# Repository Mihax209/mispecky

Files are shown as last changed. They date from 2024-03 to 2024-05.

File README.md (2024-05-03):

# MiSpecky LED Spectrum analyzer
MiSpecky is an arduino-based project for and LED strip audio spectrum analyzer. It uses hardware components for the audio frequency slicing, so it has incredibly fast response times, and not much software delay.

(The GIF takes a few moments to load...)  
MiSpecky
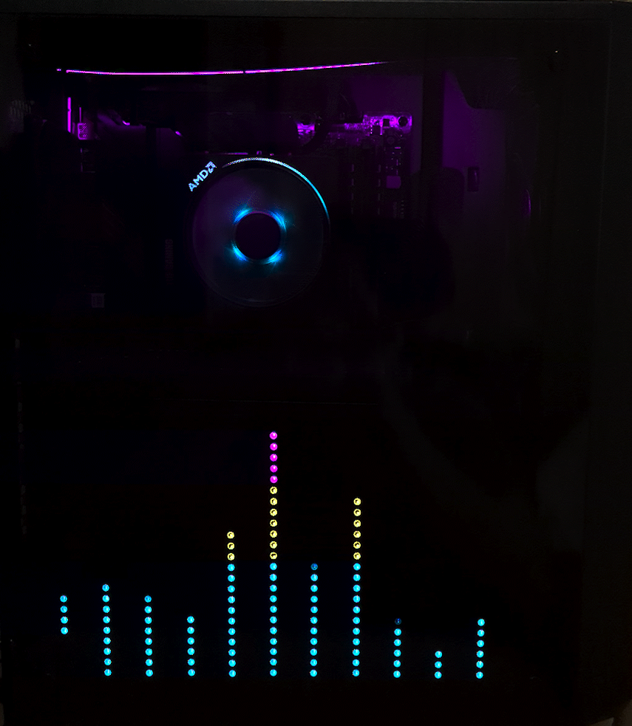
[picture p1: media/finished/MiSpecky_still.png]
MiSpecky Still


The intention was to incorporate it into my PC's case (Fractal Design Meshify C)

## Overview
The components of this project are:
- Arduino Mega Board
- Custom PCB board that acts as an shield/hat
    - along with accompanying hardware components
- LED strip assembled onto a board
- [Companion GUI controller application](https://github.com/Mihax209/mispecky-gui-controller)

## Video demonstration
This video showcases the box and companion GUI app features

https://www.youtube.com/watch?v=yOwKhR_m7uo

## Arduino+Shield Box
The PCB is basically only a carrier board for the two MSGEQ7 chips (IC1/2) responsible for the audio splicing.

The Si5351A board (U1) is just two clock generators, needed to configure the audio chararcteristics of the MSGEQ7 chips.

Next to the two knobs (potentiometers), there is a 3.5mm audio input.  
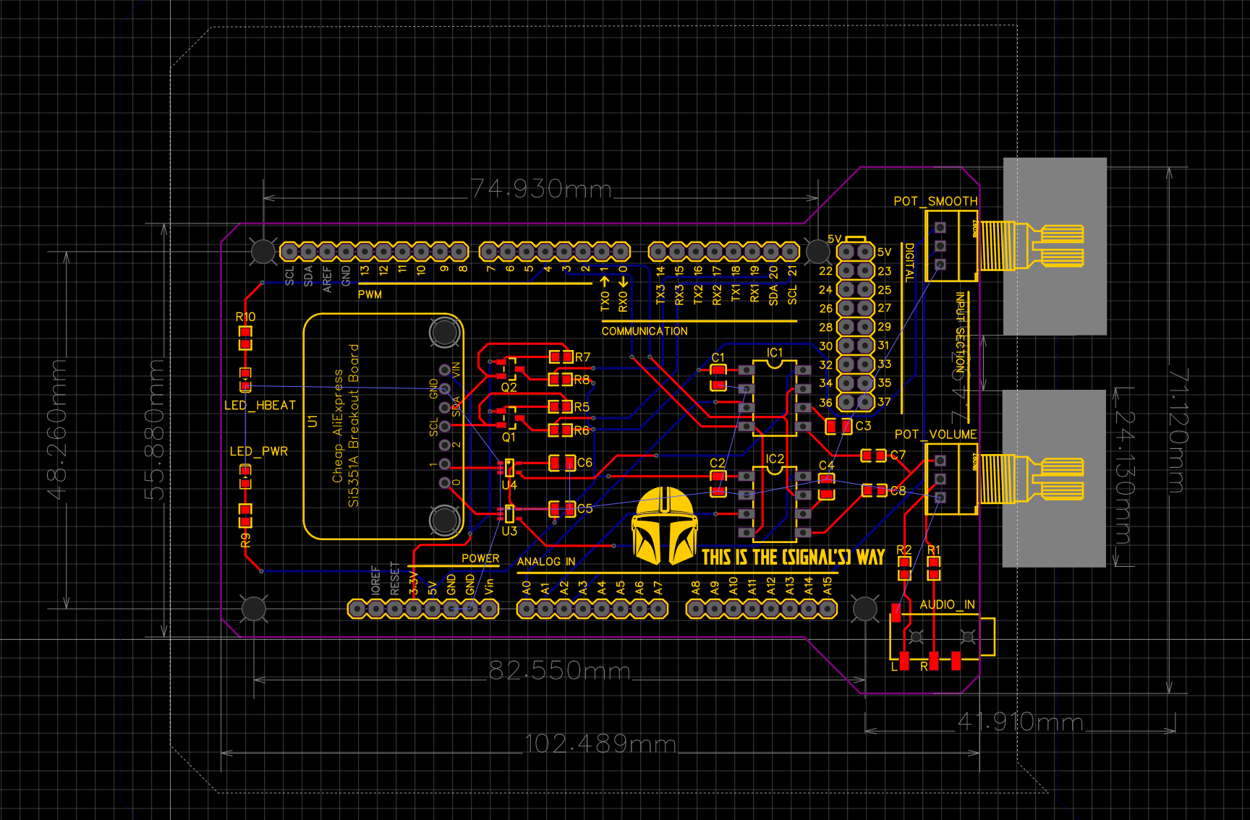
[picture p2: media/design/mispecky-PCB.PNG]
MiSpecky PCB design


With the help of my dad we've designed and 3d printed a box for the MiSpecky to sit inside, with the knobs and audio jack accessible for user input.  
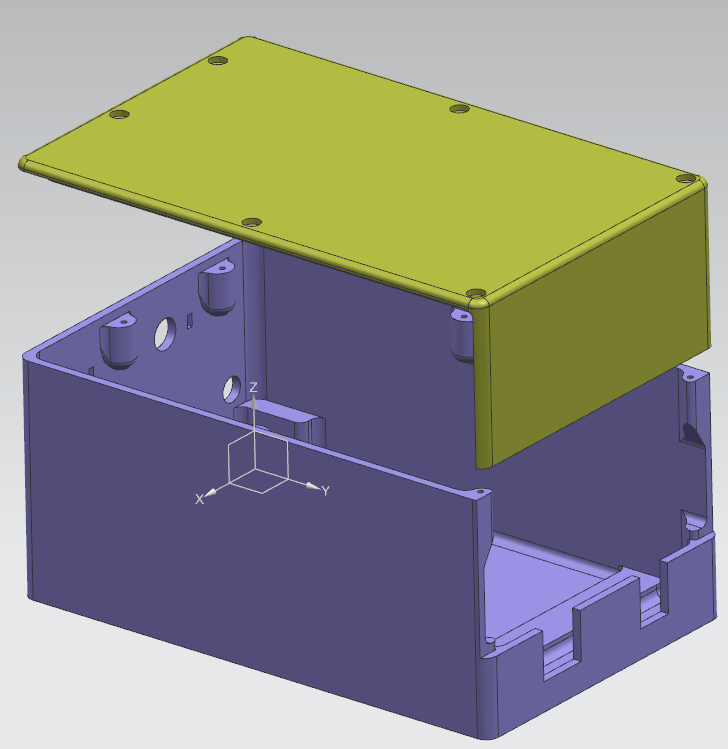
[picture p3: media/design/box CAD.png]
MiSpecky Box CAD

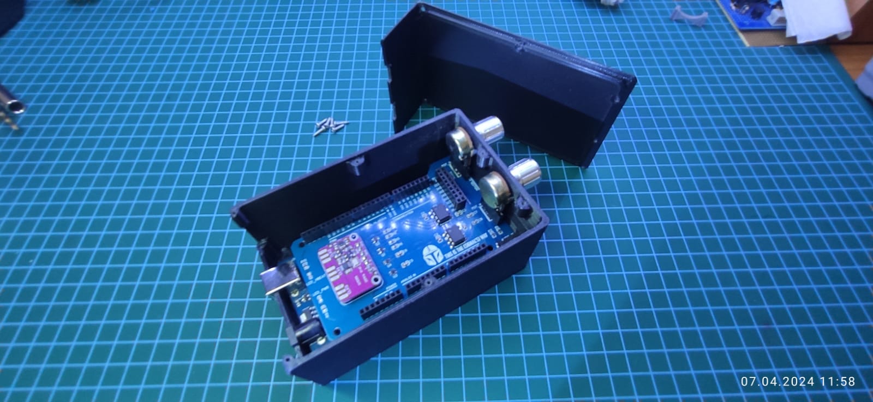
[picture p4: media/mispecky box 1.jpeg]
Assembled Arduino Box


## LED Strip Board
The LED strip board took some POC-ing to figure out how to make it look just right  
Cardboard LED poc

A lot of work as been put in to accurately measure the PC's case (and glass panel) so it would fit and hold well without any adhesives, so accessing the PC's internals is still easily possible. Once again my dad helped immensely with all of the CAD and 3d printing process.  
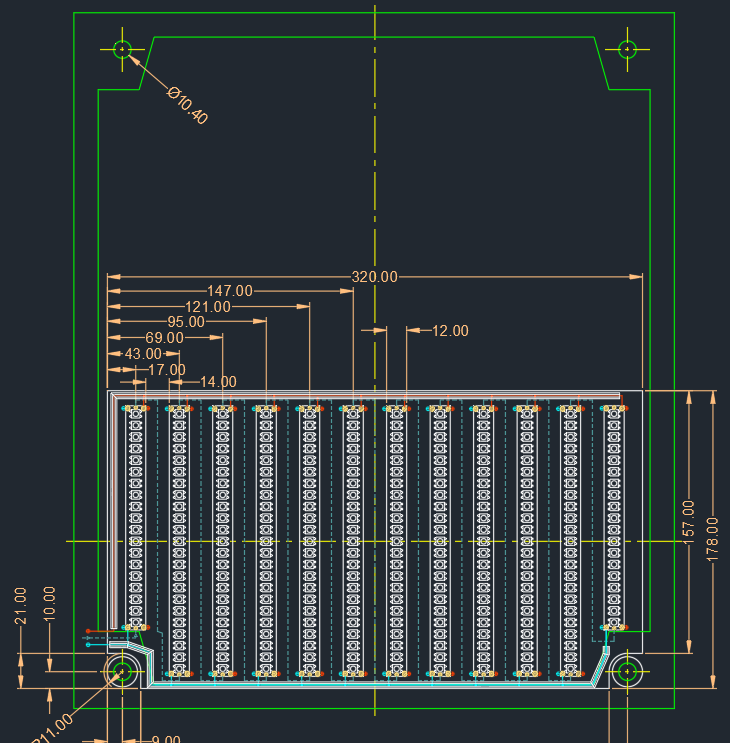
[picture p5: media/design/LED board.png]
PC measurements


The final board was constructed with a cut and painted aluminum sheet, with 3d printed grooves/trenches for the wires to follow neatly.  
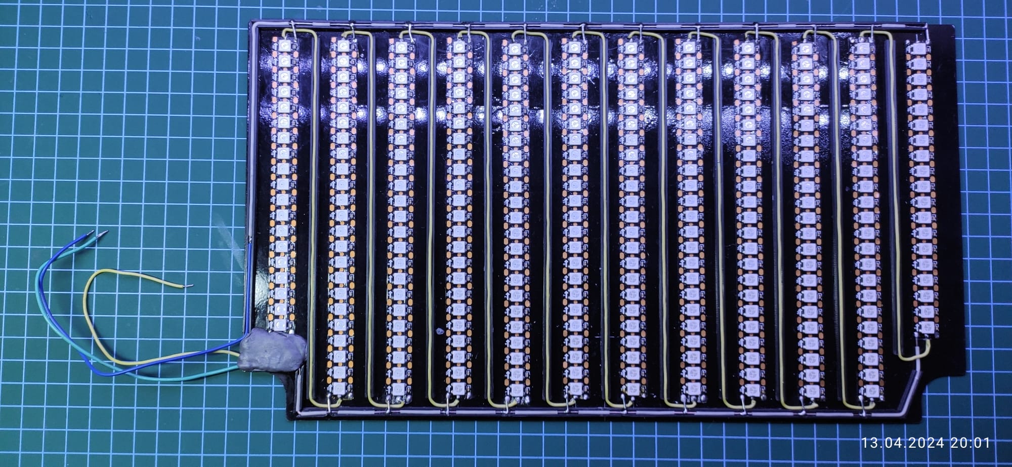
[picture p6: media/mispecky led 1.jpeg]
LED board 1

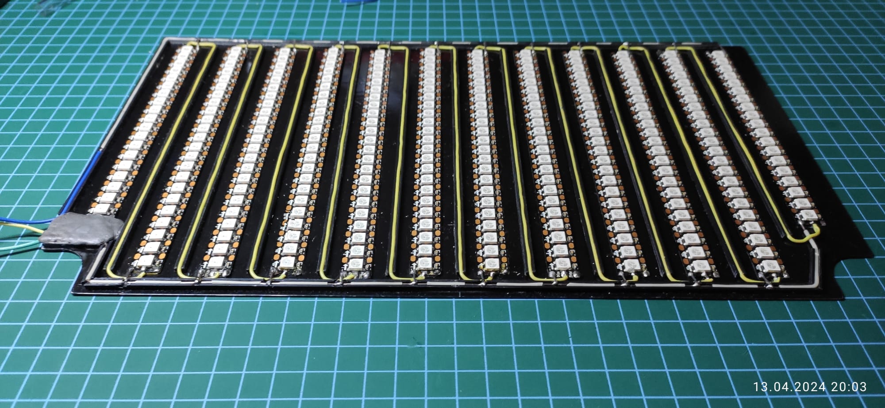
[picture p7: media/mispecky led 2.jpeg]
LED board 2


The board was then taped with black electrical tape, and dark PVC tape to completely darken everything, so only the LED lights were showing through the tinted PC glass.

## Software design
The software is composed of 3 simple modules, controlled by the main module (mispecky).
- spectrum
    - handles the MSGEQ7 chips to receive and translate audio data
- led
    - handles parsing the spectrum data into the LED lighting effect
- commands
    - handles serial port commands received from the companion GUI app, and changing the led effects as needed

## Credits
The general solution approach and initial project basis was heavily infuinced by Daniel Perez's work on his Specky Board: https://www.youtube.com/watch?v=TyE-EoX5xc8.

He goes into a lot of details and explanations on the hardware components, so I'd highly advice checking him out.

I have even been in contact with him asking some questions, so thanks a lot for helping!

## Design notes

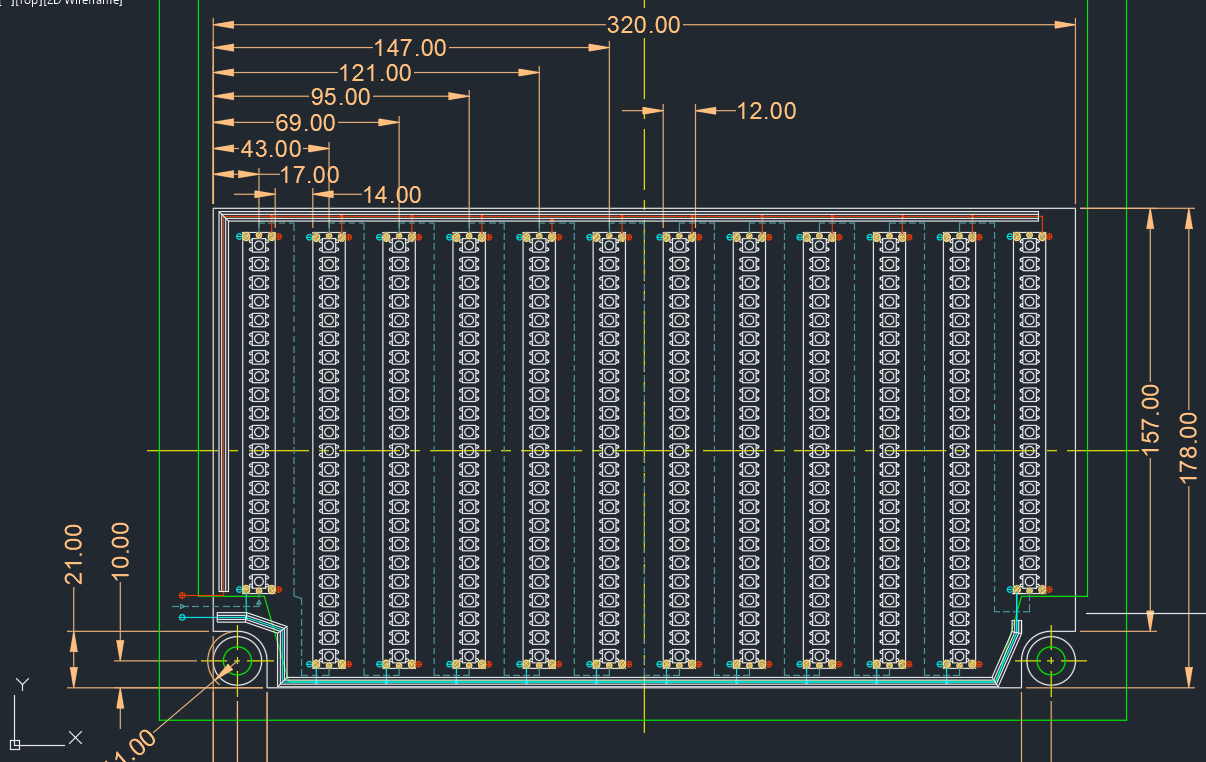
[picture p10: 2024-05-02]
media/design/LED board zoomed.png

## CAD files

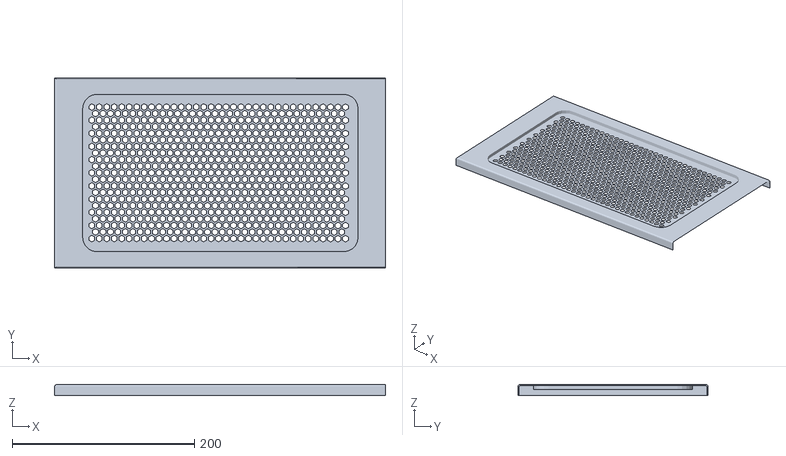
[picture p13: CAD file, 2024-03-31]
models/Meshify C TG/partial stl/Meshify FULLHaut.stl
362.8 x 208.3 x 11.8

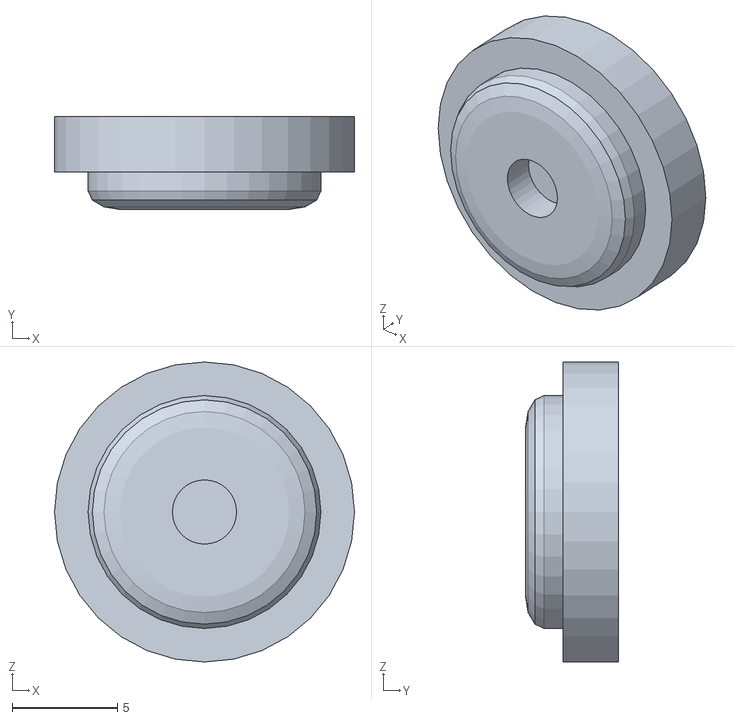
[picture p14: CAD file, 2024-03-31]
src/models/Meshify C TG/partial stl/Meshify FULLcaoutchouc_vitre_002.stl
14.3 x 4.42 x 14.3

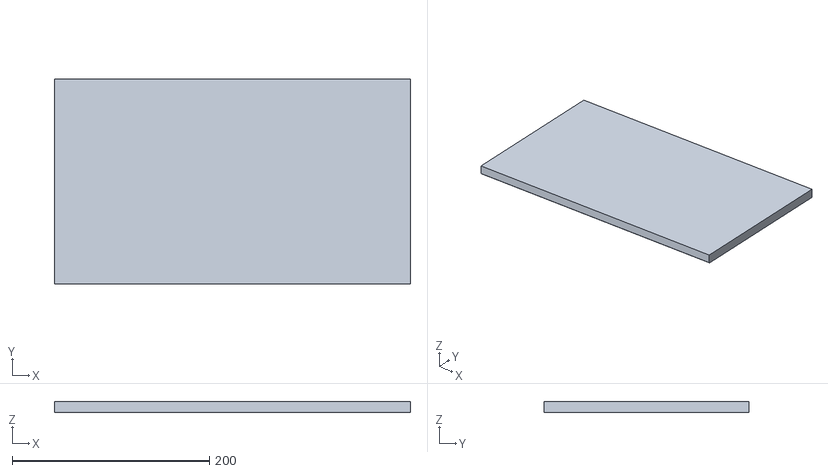
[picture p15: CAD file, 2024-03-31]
models/Meshify C TG/partial stl/Meshify FULLBas.stl
361.2 x 208.3 x 11.7

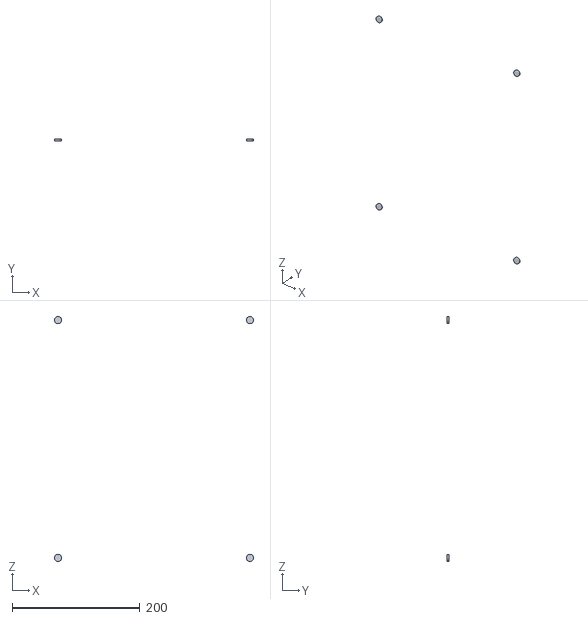
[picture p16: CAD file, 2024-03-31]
src/models/Meshify C TG/partial stl/Meshify FULLvis_TG.stl
312.2 x 3.78 x 384.0

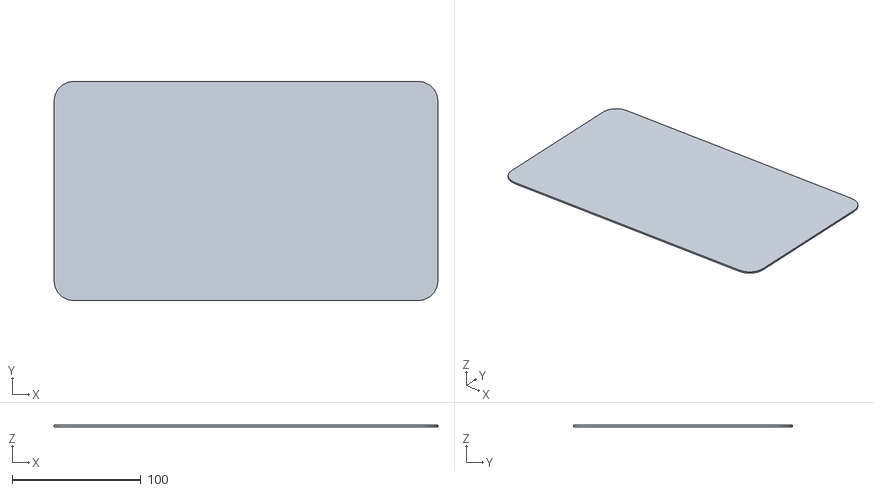
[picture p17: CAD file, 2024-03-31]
models/Meshify C TG/partial stl/Meshify FULLgrille_sup.stl
298.1 x 170.3 x 1.42

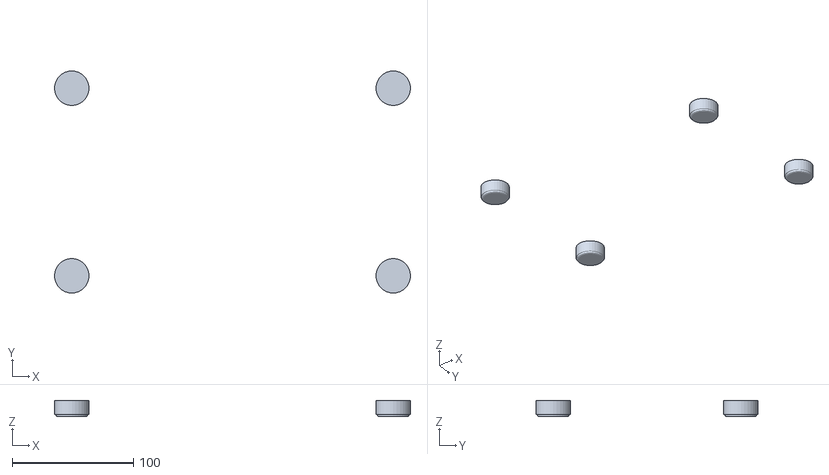
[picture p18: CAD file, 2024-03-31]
src/models/Meshify C TG/partial stl/Meshify FULLPieds_tour.stl
293.1 x 182.9 x 13.4

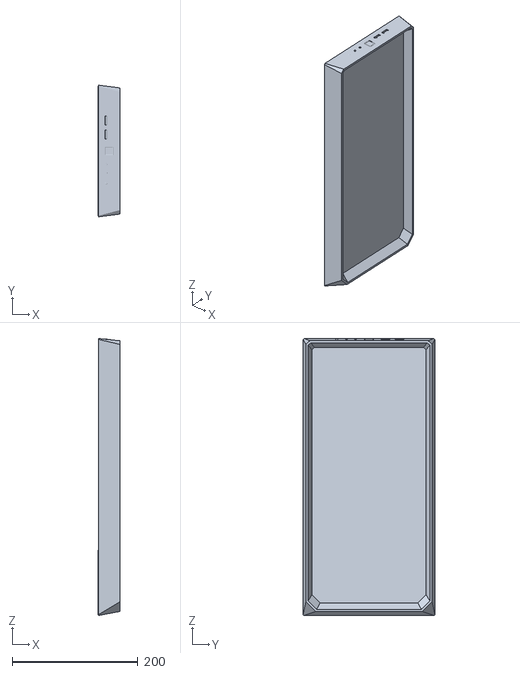
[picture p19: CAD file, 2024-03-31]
models/Meshify C TG/partial stl/Meshify FULLFront_panel_001.stl
34.2 x 209.2 x 440.0

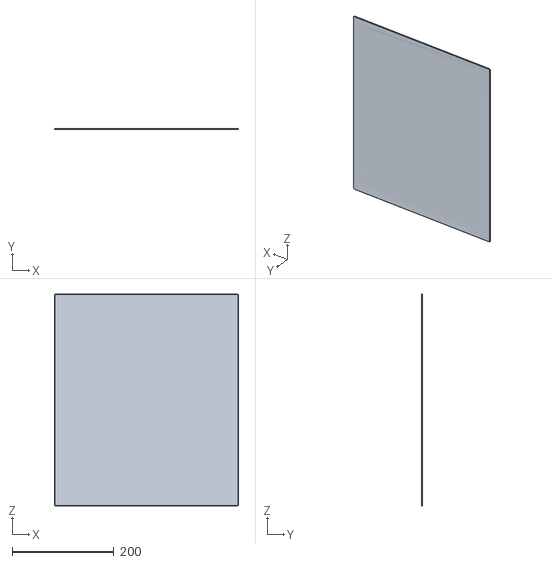
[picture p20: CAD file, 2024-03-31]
models/Meshify C TG/partial stl/Meshify FULLvitre.stl
361.6 x 2.50 x 416.3

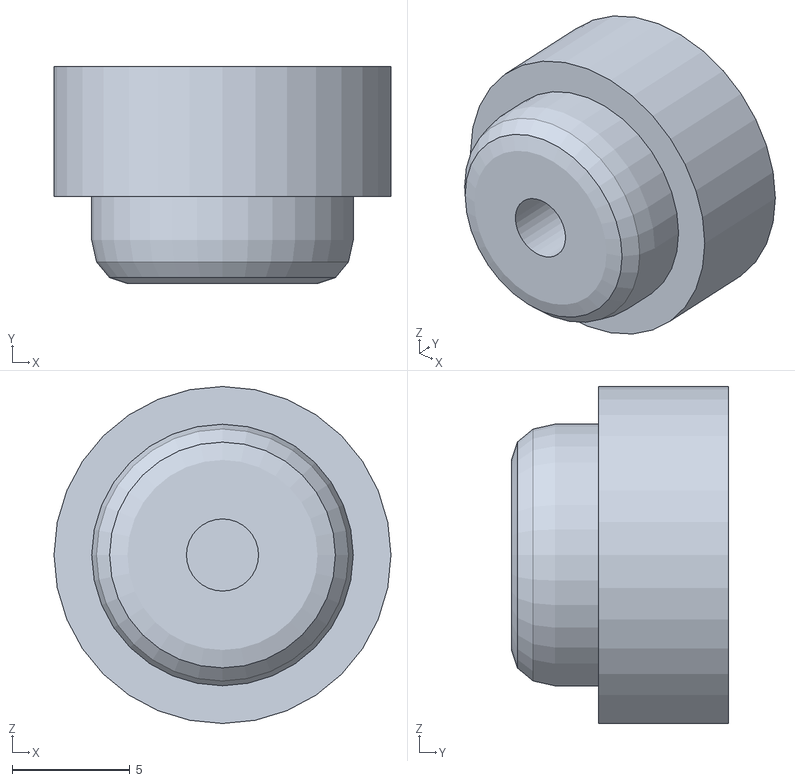
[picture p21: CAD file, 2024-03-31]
models/Meshify C TG/partial stl/Meshify FULLcaoutchouc_vitre.stl
14.3 x 9.19 x 14.3

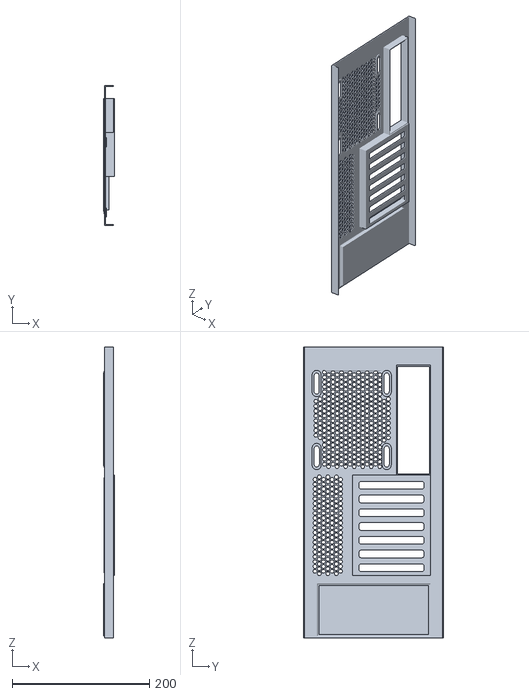
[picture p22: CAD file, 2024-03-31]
models/Meshify C TG/partial stl/Meshify FULLArriere_001.stl
16.7 x 204.2 x 424.6

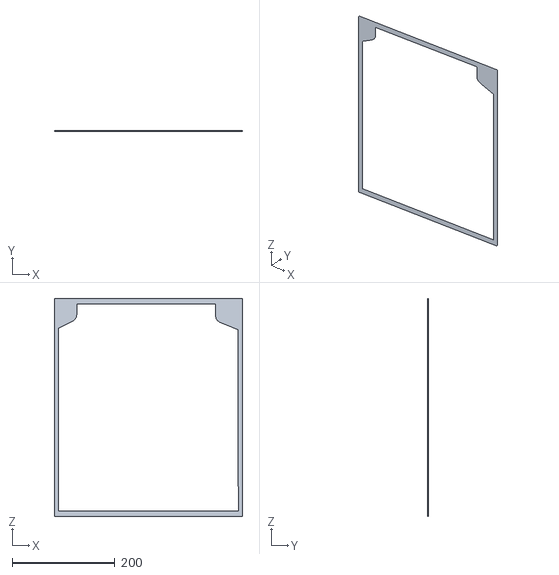
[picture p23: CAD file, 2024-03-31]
src/models/Meshify C TG/partial stl/Meshify FULLchassis_vitre.stl
367.1 x 1.99 x 424.6

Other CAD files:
models/Meshify C TG/partial stl/Meshify FULLcaoutchouc_vitre_001.stl
src/models/Meshify C TG/partial stl/Meshify FULLcaoutchouc_vitre_001.stl
models/Meshify C TG/full stl/Meshify BodyArriere_001.stl
models/Meshify C TG/full stl/Meshify BodyBas.stl
models/Meshify C TG/full stl/Meshify BodyCurve.stl
models/Meshify C TG/full stl/Meshify BodyFond.stl
models/Meshify C TG/full stl/Meshify BodyFront_panel_001.stl
models/Meshify C TG/full stl/Meshify BodyFront_panel_002.stl
models/Meshify C TG/full stl/Meshify BodyGrande_vis.stl
models/Meshify C TG/full stl/Meshify BodyGrande_vis_001.stl
models/Meshify C TG/full stl/Meshify BodyGrande_vis_002.stl
models/Meshify C TG/full stl/Meshify BodyHaut.stl
models/Meshify C TG/full stl/Meshify BodyLogo_front.stl
models/Meshify C TG/full stl/Meshify BodyPieds_tour.stl
models/Meshify C TG/full stl/Meshify BodySupport_motherboard.stl
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

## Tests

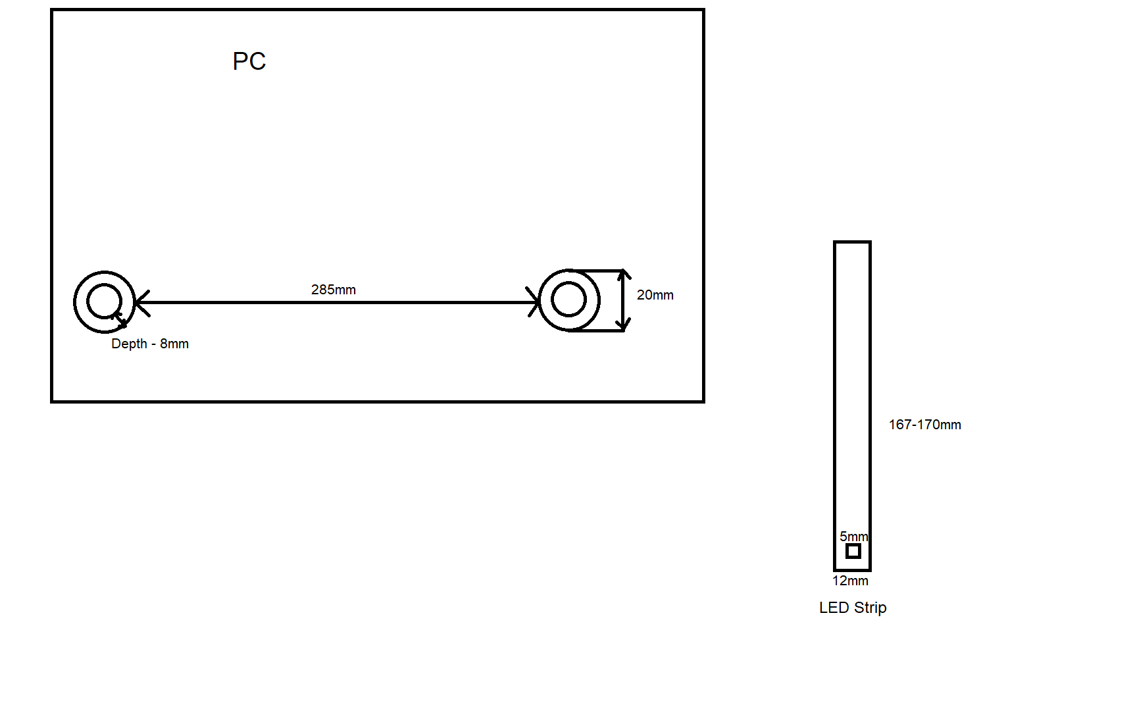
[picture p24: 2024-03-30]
media/POC/PC Measurements - mispecky.png

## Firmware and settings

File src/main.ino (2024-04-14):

#include <si5351mcu.h>
#include <FastLED.h>

// #define DEBUG

/* MACROS */
#ifdef DEBUG
#define DEBUG_DO(_x) (_x)
#else
#define DEBUG_DO(_x)
#endif

#define PRINT_INTERVAL (60)

#define LENOF(_arr) ((sizeof(_arr)) / (sizeof((_arr)[0])))

/* These definitions don't do nothing, it's just to visually see what we mean in different pin assignments */
#define ANALOG(x)   (x)
#define DIGITAL(x)  (x)

/* PINS */
#define RESET_PIN   DIGITAL(2)      // Pin to instruct MSGEQ7 to return to band zero and inspect it
#define STROBE_PIN  DIGITAL(3)      // Pin to instruct MSGEQ7 IC's to inspect next band (band 0 thru 6)
#define HBEAT_PIN   DIGITAL(4)      // Pin for the hearbteat LED
#define DATA_PIN    DIGITAL(5)      // Pin for serial communication with LED string
#define MSGEQ0_PIN  ANALOG(0)
#define MSGEQ1_PIN  ANALOG(1)
#define BRIGHT_PIN  ANALOG(4)
#define SMOOTH_PIN  ANALOG(2)

/* EQ CONFIG */
#define EQ_BANDS    (14)
#define NOISECOMP   (70)
#define GAIN        (1.2)
#define EQ_DELTA    (5.0)

/* LED CONFIG */
#define ROWS                    (23)
#define COLUMNS                 (12)
#define AMOUNT_TRIMMED          (4)
#define DEFAULT_BRIGHT          (1)
#define MAX_BRIGHTNESS          (35)
#define PEAK_INDICATOR_TIMEOUT  (25)

enum color_effect {
    DEFAULT_COLOR,
    INVERTED_COLOR,
    VERTICAL_GRADIENT,
    HORITZONTAL_GRADIENT,
};

enum serial_commands {
    BRIGHTNESS_COMMAND='B'
};

/* GLOBAL VARIABLES */
Si5351mcu Si;
int MSGEQ_Bands[EQ_BANDS] = {0};
bool lit_matrix[COLUMNS][ROWS];
struct CRGB color_matrix[COLUMNS][ROWS];
struct CRGB fastLED_matrix[(COLUMNS*ROWS) - (2*AMOUNT_TRIMMED)];
uint8_t peak_indicators[COLUMNS] = {0};
unsigned int peak_indicators_timeout[COLUMNS] = {0};
float prev_column_values[COLUMNS] = {0};
bool g_peak_indicators_enabled = false;
int g_curr_bright_analog = 0;
int g_curr_brightness = DEFAULT_BRIGHT;

/* ----------------------------------- SETUP ----------------------------------- */

void setup()
{
    Serial.begin(115200);
    DEBUG_DO(Serial.println("Start of init"));

    /* Clock generator init */
    /* NOTE: clock 0 is MSGEQ7 1 board-wise (oopsie) */
    Si.init(25000000L);
    Si.setFreq(0, 165000);
    Si.setFreq(1, 104000);
    Si.setPower(0, SIOUT_8mA);
    Si.setPower(1, SIOUT_8mA);
    Si.enable(0);
    Si.enable(1);

    /* FastLED library init */
    FastLED.addLeds<WS2812B, DATA_PIN, GRB>(fastLED_matrix, LENOF(fastLED_matrix));
    updateBrightness(DEFAULT_BRIGHT);

    /* pin configurations */
    pinMode(HBEAT_PIN, OUTPUT);
    pinMode(DATA_PIN, OUTPUT);
    pinMode(STROBE_PIN, OUTPUT);
    pinMode(RESET_PIN, OUTPUT);

    /* LED matrix init */
    setColorMatrix(INVERTED_COLOR);

    DEBUG_DO(Serial.println("init completed"));
}

/* ----------------------------------- LOOP ----------------------------------- */

unsigned long loop_counter = 0;
void loop()
{
    checkSerial();
    readMSGEQ7();
    updateLEDMatrix();

    digitalWrite(HBEAT_PIN, HIGH);
    delay(20);
    digitalWrite(HBEAT_PIN, LOW);
    delay(10);

    ++loop_counter;
    if (1000000 == loop_counter)
        loop_counter = 0;
}

/* ----------------------------------- FUNCTIONS ----------------------------------- */

void checkSerial()
{
    if (Serial.available() <= 0) {
        return;
    }

    String input_string = Serial.readStringUntil('\n');

    if (input_string.charAt(1) != ' ') {
        Serial.println("ERROR: invalid command format");
        return;
    }

    char command_char = input_string.charAt(0);
    String command_data = input_string.substring(2);
    switch (command_char)
    {
    case BRIGHTNESS_COMMAND:
        checkAndUpdateBrightness(command_data);
        break;
    default:
        Serial.print("Invalid command: "); Serial.println(command_char);
    }
}

void checkAndUpdateBrightness(String& value_str)
{
    int value = atoi(value_str.c_str());
    if ((value > 100) || (value < 0)) {
        Serial.print("ERROR: brightness should be between 0 and 100 (got ");
        Serial.print(value); Serial.println(")");
        return;
    }

    int new_brightness = (int)map(value, 0, 100, 0, MAX_BRIGHTNESS);

    updateBrightness(new_brightness);
}

void updateBrightness(int brightness)
{
    g_curr_brightness = brightness;
    FastLED.setBrightness(brightness);
    DEBUG_DO(Serial.print("Brightness updated to: "));
    DEBUG_DO(Serial.println(brightness));
}

void setColorMatrix(enum color_effect effect) 
{
    switch (effect) {
    case DEFAULT_COLOR:
        defaultColor();
        break;
    case INVERTED_COLOR:
        invertedColor();
        break;
    case VERTICAL_GRADIENT:
        verticalGradientColor();
        break;
    case HORITZONTAL_GRADIENT:
        horizontalGradientColor();
        break;
    default:
        DEBUG_DO(Serial.print("ERROR! got to updateColorMatrix with effect num: "));
        DEBUG_DO(Serial.println(effect));

        defaultColor();
        break;
    }
}

void defaultColor()
{
    for (int col = 0; col < COLUMNS; ++col) {
        for (int row = 0; row < ROWS; ++row) {
            color_matrix[col][row] = 
                (row < 11) ? CRGB::Cyan : (row < 18 ? CRGB::Magenta : CRGB::Yellow);
        }
    }
}

void invertedColor()
{
    for (int col = 0; col < COLUMNS; ++col) {
        for (int row = 0; row < ROWS; ++row) {
            color_matrix[col][row] = 
                (row < 11) ? CRGB::Cyan : (row < 18 ? CRGB::Yellow : CRGB::Magenta);
        }
    }
}

void verticalGradientColor()
{
    int start_hue = 235;
    int end_hue = 5;

    int curr_hue = start_hue;
    for (int row = 0; row < ROWS; ++row) {
        for (int col = 0; col < COLUMNS; ++col) {
            color_matrix[col][row] = CHSV((uint8_t)curr_hue, 255, 255);
        }

        curr_hue += (end_hue - start_hue) / ROWS;
    }
}

void horizontalGradientColor()
{
    int start_hue = 240;
    int end_hue = 0;

    int curr_hue = start_hue;
    for (int col = 0; col < COLUMNS; ++col) {
        for (int row = 0; row < ROWS; ++row) {
            color_matrix[col][row] = CHSV((uint8_t)curr_hue, 255, 255);
        }

        curr_hue += (end_hue - start_hue) / COLUMNS;
    }
}

void updateLEDMatrix()
{
    for (int col = 0; col < COLUMNS; ++col) {
        int height = min(getColumnHeight(col), ROWS);
        /* light up EQ band */
        for (int row = 0; row < ROWS; ++row) {
            lit_matrix[col][row] = (row < height);
        }

        if (g_peak_indicators_enabled) {
            /* add peak indicator */
            if (height > peak_indicators[col] ||
                peak_indicators_timeout[col] > PEAK_INDICATOR_TIMEOUT
            ) {
                peak_indicators[col] = height;
                peak_indicators_timeout[col] = 0;
                lit_matrix[col][peak_indicators[col]] = false;
            }
            else {
                peak_indicators_timeout[col]++;
                lit_matrix[col][peak_indicators[col]] = true;
            }
        }

        if (shouldPrint()) {
            DEBUG_DO(Serial.print("Column height: "));
            DEBUG_DO(Serial.print(height));
            DEBUG_DO(Serial.print(". Peak: "));
            DEBUG_DO(Serial.print(peak_indicators[col]));
            DEBUG_DO(Serial.print(" ("));
            DEBUG_DO(Serial.print(peak_indicators_timeout[col]));
            DEBUG_DO(Serial.println(")"));
        }
    }

    int ignore_cnt = 0;
    for (int col = 0; col < COLUMNS; ++col) {
        for (int row = 0; row < ROWS; ++row) {
            int flat_index = (col * ROWS) + row - AMOUNT_TRIMMED;

            if (flat_index >= 0) {
                fastLED_matrix[flat_index] =
                    lit_matrix[col][row] ? color_matrix[col][row] : CRGB::Black;
            }
        }
    }

    FastLED.show();
}

/* NOTE: THIS WILL NEED TO BE CHANGED ACCRODING TO AMOUNT OF COLUMNS */
int getColumnHeight(int column) {
    /* This is a 14 -> 12 band convertor */
    float current, previous, value = 0;
    float alpha = mapToFloat(analogRead(SMOOTH_PIN), 0, 1023, 1.0, 0.1);
    // float alpha = 0.4;

    previous = prev_column_values[column];
    current = MSGEQ_Bands[column + 1];
    if (column == 0) {
        // Bass average with invisible band
        current = max(current, MSGEQ_Bands[0]);
    }
    current /= EQ_DELTA;

    value = (current * alpha) + (prev_column_values[column] * (1.0-alpha));
    prev_column_values[column] = value;

    return min(ROWS, (int)value);
}


void readMSGEQ7(void)
{
    digitalWrite(RESET_PIN, HIGH); // Part 1 of Reset Pulse. Reset pulse duration must be 100nS minimum.
    digitalWrite(RESET_PIN, LOW);  // Part 2 of Reset pulse. These two events consume more than 100nS in CPU time.

    DEBUG_DO(printBandPrologue());

    for (int band = 0; band < EQ_BANDS; band++)
    {                                                  // Loop that will increment counter that AnalogRead uses to determine which band to store data for.
        digitalWrite(STROBE_PIN, LOW);                 // Re-Set Strobe to LOW on each iteration of loop.
        delayMicroseconds(30);                         // Necessary delay required by MSGEQ7 for proper timing.
        MSGEQ_Bands[band] = max(0, analogRead(MSGEQ0_PIN) - NOISECOMP) * GAIN;
        DEBUG_DO(printBandValue(band, MSGEQ_Bands[band]));

        ++band;
        MSGEQ_Bands[band] = max(0, analogRead(MSGEQ1_PIN) - NOISECOMP) * GAIN;
        DEBUG_DO(printBandValue(band, MSGEQ_Bands[band]));

        digitalWrite(STROBE_PIN, HIGH);
    }
}

bool shouldPrint()
{
    return (0 == (loop_counter % PRINT_INTERVAL));
}

void printBandPrologue()
{
    if (shouldPrint()) {
        DEBUG_DO(Serial.print("\n\n\n\n\n\n"));
        DEBUG_DO(Serial.print("--"));
        DEBUG_DO(Serial.print(loop_counter));
        DEBUG_DO(Serial.print("-- Brightness: "));
        DEBUG_DO(Serial.print(g_curr_brightness));
        DEBUG_DO(Serial.println());
    }
}

void printBandValue(int band, int value)
{
    if (shouldPrint()) {
        DEBUG_DO(Serial.print(band));
        if (band < 10) {
            DEBUG_DO(Serial.print(": "));
        }
        else {
            DEBUG_DO(Serial.print(":"));
        }

        DEBUG_DO(Serial.print(MSGEQ_Bands[band]));
        DEBUG_DO(Serial.println());
    }
}

float mapToFloat(int value, int in_min, int in_max, float out_min, float out_max) {
    return ((float)value - (float)in_min) * ((float)out_max - (float)out_min) / ((float)in_max - (float)in_min) + (float)out_min;
}

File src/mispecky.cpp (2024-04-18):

#include <Arduino.h>
#include <FastLED.h>
#include <limits.h>

#include <common.h>
#include <commands.h>
#include <spectrum.h>
#include <led.h>

/* Function declarations */
void blinkHeartbeat();
void incGlobalLoopCounter();

/* Global variables */
unsigned long global_loop_counter = 0;

/* ----------------------------------- SETUP ----------------------------------- */

void setup()
{
    Serial.begin(115200);
    DEBUG_DO(Serial.println("Start of init"));

    SPECTRUM_init();

    LED_init();
    LED_setColorMatrix(DEFAULT_COLOR);

    /* pin configurations */
    pinMode(HBEAT_PIN, OUTPUT);
    pinMode(DATA_PIN, OUTPUT);
    pinMode(STROBE_PIN, OUTPUT);
    pinMode(RESET_PIN, OUTPUT);

    global_loop_counter = 0;

    DEBUG_DO(Serial.println("init completed"));
}

/* ----------------------------------- LOOP ----------------------------------- */

void loop()
{
    COMMANDS_checkSerialCommands();
    SPECTRUM_sampleSpectrum();
    LED_updateLEDMatrix();

    incGlobalLoopCounter();
}

void incGlobalLoopCounter()
{
    global_loop_counter++;
    if (ULONG_MAX == global_loop_counter) {
        global_loop_counter = 0;
    }
}

/* LEGACY, unused anymore */
void blinkHeartbeat()
{
    digitalWrite(HBEAT_PIN, HIGH);
    delay(20);
    digitalWrite(HBEAT_PIN, LOW);
    delay(10);
}

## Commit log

2020-10-17 original specky board code
2024-03-31 add stl files and overlay pictures
    [Meshify BodyArriere_001.stl, Meshify BodyBas.stl, Meshify BodyCurve.stl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]
2024-03-31 add peak indicators (still buggy)
    [main.ino]
2024-04-07 change to inverted color
    [main.ino]
2024-04-07 change brightness hysteresis to pin values
2024-04-10 house cleaning
    [Meshify BodyArriere_001.stl, Meshify BodyBas.stl, Meshify BodyCurve.stl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]
2024-04-10 add pcb and images
    [Gerber_BoardOutline.GKO, Gerber_BottomLayer.GBL, Gerber_BottomSilkLayer.GBO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]
2024-04-13 fix amount trimmed bug, update amount trimmed
    [main.ino]
2024-04-13 update arduino COM port
2024-04-15 migrate to platformio
    [Gerber_BoardOutline.GKO, Gerber_BottomLayer.GBL, Gerber_BottomSilkLayer.GBO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]
2024-04-15 fix empty serial command data bug
    [mispecky.cpp]
2024-04-15 major folder restreucture and refactor
    [Gerber_BoardOutline.GKO, Gerber_BottomLayer.GBL, Gerber_BottomSilkLayer.GBO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]
2024-04-17 change led effect order
2024-04-18 remove broken peak indicator
    [led.cpp]
2024-05-02 add power limit for LEDs
